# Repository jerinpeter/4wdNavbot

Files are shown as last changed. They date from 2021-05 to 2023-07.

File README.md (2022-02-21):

# A 4WD ROS Robot with autonomous navigation capability

## The Robot Harware Setup 🔧

|||
| :-----: | :-: |
| |  |
|| 

## Installation 💻

```
cd ~/catkin_ws/src

git clone https://github.com/jerinpeter/4wdNavbot.git

cd ..

catkin_make

rosdep install --from-paths src --ignore-src -r -y

```
If catkin_make shows error, install the missing dependenices using the rosdep command.  

## 3D modelling and Simulation 
The Robot was modelled in Fusion360 and converted to URDF using [fusion2urdf](https://github.com/syuntoku14/fusion2urdf).
Gazebo Pluggins for [differential drive](http://gazebosim.org/tutorials?tut=ros_gzplugins#DifferentialDrive),Odometry and [LaserScan](http://gazebosim.org/tutorials?tut=ros_gzplugins#Laser) were added to the urdf and tested in a custom made simulation environment/world in Gazebo.

### Demo video 👇

GAZEBO SIMULATION (https://www.youtube.com/watch?v=yLzaqpGkmrI)

# Simulation Setup
## Mapping 
Open a new terminal window and split it accordingly if using terminator,run the following commands 
```
roslaunch navbot_description gazebo.launch

roslaunch gmapping mapping.launch

rosrun teleop_twist_keyboard teleop_twist_keyboard.py

rviz

rosrun map_server map_saver -f newmap
```
The map is already saved in /navbot_description/maps directory if using the preset map.

## Navigation
```
roslaunch navbot_description gazebo.launch

roslaunch navbot_navigation move_base.launch

rviz

```
* After opening Rviz open the configuration file from the Rviz folder.
* Type rqt in terminal and open dynamic reconfigure pluggin, load the final_reconf_param_sim.yaml from the reconf_params folder and you are all set to give navigation goals.

# Working in brief
### Note: BOM and references are attached towards the end.

* Starting from the low-level control the Robot uses an **Arduino Mega** takes **cmd_vel** from the Jetson Nano via **ros-serial** via USB. The Arduino is also responsible for reading the encoder values and publishing it back to the Jetson Nano.
### Topics published and subscribed by Arduino
```
/cmd_vel
/right_ticks
/left_ticks 
```
* I have used **RMCS-2303** Motor drivers for controlling the Dc motors with encoders. The motor driver has inbuilt PID control implemented with the help of an STM32 MicroController.
*  The Motor driver is connected to Arduino via **UART** (Tx,RX).4 such motor drivers where used to control the 4 motors and each motors where addresed using a **unique slave-id** set via jumper pins.
* The main advantage of using this motors were that only 3 wires (Tx,Rx,Gnd) was required to control all the 4 motors,vary its speed and read the encoder values.

Motortests

* The High level control is Nvidia Jetson Nano which runs on [Jetpack](https://developer.nvidia.com/embedded/jetpack) based on ubuntu 18.04 with [ROS Melodic](http://wiki.ros.org/melodic/Installation/Ubuntu) installed.

* The Lidar is also connected to the Jetson Nano via Usb and the whole system is powered using 5v from a buck converter that steps down 12.6v from the Li-Ion Battery pack to 5V 4 amps max to power the Jetson Nano.

## ROS Setup for Mapping and Navigation 

* The arduino publishes the encoder ticks into the Jetson Nano via ros-serial which are subscribed by the [differential_drive](http://wiki.ros.org/differential_drive) package and publishes **/odom** as well as **Tf** **(odom -> base_footprint)**.

The YdLidar package is responsible for publishing the LaserScan as **/scan** data along with **Tf** **(base_link -> laser)**

### **Tf Tree**
* With the Robot Model
Tf_tree_sim

* Without Robot Model

    

# Real Robot Setup

* Before setting up and running the robot,Jetson Nano and host machine should be set up following this tutorial -> [ROS Network setup](http://wiki.ros.org/ROS/NetworkSetup)

```
roscore

rosrun rosserial_python serial_node.py /dev/ttyACM0

roslaunch ydlidar_ros yd_lidar.launch

roslaunch differential_drive tf_controller.launch

roslaunch navbot_navigation move_base.launch

rviz

```

* After running Rviz open the Navbot.rviz configuration from the Rviz folder.

* Open DynamicReconfigure from rqt gui and load final_reconf_params_real.yaml

* Give the goal location in Rviz and we are good to go!

## Components Used

| Component | Image |
| --- |:---:|
| [Nvidia Jetson Nano](https://www.tannatechbiz.com/nvidia-jetson-nano-developer-kit-b01.html) || 
| [YD-Lidar X4](https://www.amazon.in/SmartFly-info-LIDAR-053-YDLIDAR-X4/dp/B07DBYHJVQ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)|| 
|[Arduino Mega](https://robu.in/product/arduino-mega-2560-board-with-compatible-usb-cable/)|| 
| [RMCS 2303 Motor Drivers](https://robokits.co.in/motor-drives-drivers/encoder-dc-servo/rhino-dc-servo-driver-10v-30v-50w-5a-compatible-with-modbus-uart-ascii-for-encoder-dc-servo-motor)|
| [100 RPM High Precision Encoder Motors](https://robokits.co.in/motors/encoder-dc-servo/high-torque-high-precision-motor/high-torque-high-precision-encoder-dc-geared-motor-12v-100rpm)|
|[10,000Mah, 2C Li-Ion Battery](https://robokits.co.in/batteries-chargers/skycell-li-ion-battery/11.1vli-ion-batteries-9.6-12.6v/li-ion-11.1v-10000mah-2c-with-inbuilt-charger-protection) |
|[DC-DC Step Down Converter](https://robu.in/product/10a-dc-dc-step-down-adjustable-constant-voltage-module/) |
|[125mm AGV Wheels](https://robokits.co.in/robot-wheels/rubber-tracked-wheels/robot-wheel-125mm-diameter-60mm-width-for-atv) | 

## Further Work

* Modularize all the nodes into launch files for ease of use.
* Addition of the dynamic reconfigure parameters into the navigation param files.
* Using IMU and EKF for better Localization and pose estimate.
* Adding Kinect / realsense for 3D mapping,Vision applications etc.
* Addition of return to base station for charging feature.

## References

[RMCS 2303 Motor Driver Manual](https://robokits.download/downloads/RMCS-2303%20updated%20datasheet.pdf)

[RMCS 2303 Arduino Library](https://robokits.co.in/downloads/RMCS2303drive_V2.zip)

[Motor Specifications](https://robokits.download/downloads/RMCS-5013.pdf)

[ROS Navigation Tuning Guide](https://kaiyuzheng.me/documents/navguide.pdf)

[Map Float Arduino Library](https://github.com/radishlogic/MapFloat)

## [Project Photos and Videos](https://photos.app.goo.gl/16n6vmuHw6YWK7ry7)

* The photos and videos that I took during the build, will make a final video soon!

# UPDATE 12-11-2021 
 
 ## Support for Odom from T265 + TF correction

* Added Support for using Odom from Intel RealSense T265 Tracking Camera
* Added the required TF Launch files for the same
    * To use Odometry from T265 run these extra commands

 ```
roslaunch navbot_navigation tf.launch 

 ```  

 ## UPDATED Base Local Planner -> DWA to TEB

* Updated parameters can be found in the params folder

To install the same use
```
sudo apt-get install ros-noetic-teb-local-planner
```

## Added support for Xbox 360 Kinect for 3D vision -> RTAB mapping, Point Cloud Generation

[Kinect Drivers + ROS Package installation](https://aibegins.net/2020/11/22/give-your-next-robot-3d-vision-kinect-v1-with-ros-noetic/)

* After installtion the following command will open up the depth stream / PointCloud in Rviz

```
roslaunch freenect_launch freenect.launch depth_registration:=true
```

## FINAL WORKING VIDEO [Outdoor Navigation + 3D Point Cloud Generation] 👇

Final Video (https://youtu.be/Dy9fhVJdwMo)

## Contributions

Contributions are most welcome ;-)

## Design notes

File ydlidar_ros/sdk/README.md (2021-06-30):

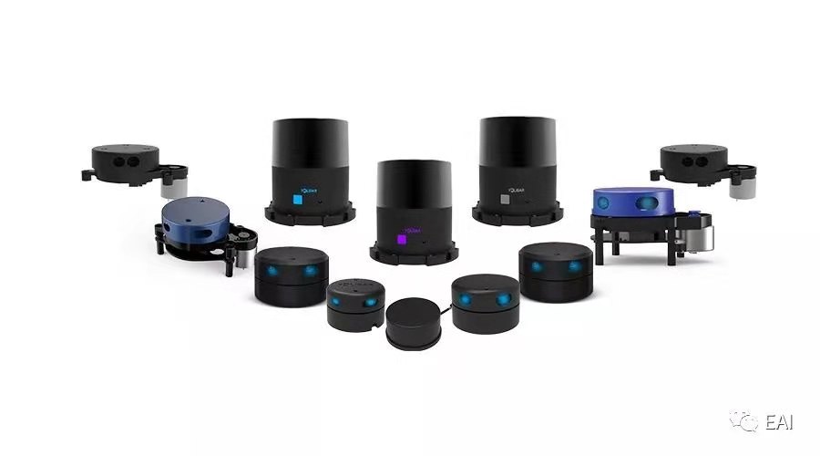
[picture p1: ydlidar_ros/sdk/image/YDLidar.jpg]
YDLIDAR


YDLIDAR SDK   
=====================================================================

# 1 Introduction

YDLIDAR(https://www.ydlidar.com/) series is a set of high-performance and low-cost LIDAR sensors, which is the perfect sensor of 2D SLAM, 3D reconstruction, multi-touch, and safety applications.

If you are using ROS (Robot Operating System), please use our open-source [ROS Driver]( https://github.com/ydlidar/ydlidar_ros) .

## 1.1 Prerequisites
* Linux
* Windows 7/10, Visual Studio 2015/2017
* C++11 compiler

## 1.2 Release Notes
| Title |  Version |  Data |
| :--- | ---:|  :--: |
| SDK |  1.4.7 | 2020-03-31  |

- [feature] support new Lidar G5 and G7.

# 2 YDLidar SDK Communication Protocol
YDLidar SDK communication protocol opens to all users. It is the communication protocol between user programs and YDLIDAR products. The protocol consists of control commands and data format. Please refer to the [YDLidar SDK Communication Protocol](include/ydlidar_protocol.h) for detailed information.

# 3 YDLidar SDK

YDLidar SDK provides the implementation of control commands and Laser scan data transmission, as well as the C/C++ API. The basic structure of YDLidar SDK is shown as below:

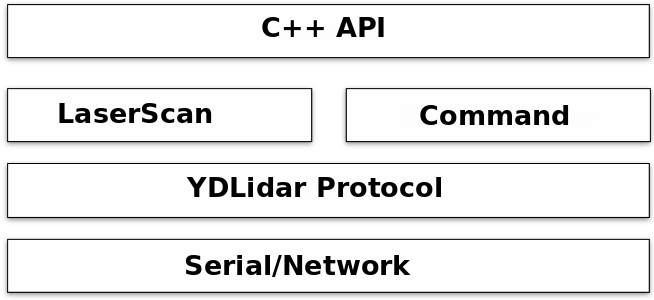
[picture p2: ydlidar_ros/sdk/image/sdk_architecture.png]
YDLidar SDK Architecture


 Serial or network is used for communication between YDLidar SDK and LiDAR sensors. Please refer to the YDLidar SDK Communication Protocol for further information. LaserScan supports Laser Scan Data transmission, while Command handler receives and sends control commands. And the C++ API is based on Command and LaserScan Hander.

The YDLidar LiDAR sensors can be connected to host directly by serial or through the YDLidar Adapter board. YDLidar SDK supports both connection methods. When LiDAR units are connected to host directly by Serial, the host will establish communication with each LiDAR unit individually. And if the LiDAR units connect to host through Adapter board, then the host only communicates with the YDLidar Adapter board while the Adapter Board communicates with each LiDAR unit.

# 4 YDLidar SDK API

YDLidar SDK API provides a set of C++ style functions which can be conveniently integrated in C/C++ programs. Please refer to the [YDLidar SDK API Reference](doc/html/index.html) for further information.

## 4.1 Installation
The installation procedures in Ubuntu 18.04/16.04/14.04 LTS and Windows 7/10 are shown here as examples. For Ubuntu 18.04/16.04/14.04 32-bit LTS and Mac, you can get it in [YDLidar-SDK wiki](https://github.com/YDLIDAR/YDLidar-SDK/wiki).
### 4.1.1 Ubuntu 18.04/16.04/14.04 LTS
#### Dependencies
YDLidar SDK requires [CMake 2.8.2+](https://cmake.org/) as dependencies. You can install these packages using apt:
```
sudo apt install cmake pkg-config
```
#### Compile YDLidar SDK
In the YDLidar SDK directory, run the following commands to compile the project:
```
git clone https://github.com/YDLIDAR/sdk.git
cd sdk/build
cmake ..
make
sudo make install
```
### 4.1.2 Windows 7/10
#### Dependencies
YDLidar SDK supports Visual Studio 2015/2017 and requires [CMake 2.8.2+](https://cmake.org/) as dependencies. [vcpkg](https://github.com/Microsoft/vcpkg) is recommended for building the dependency libraries as follows:
For the 32-bit project:
```
.\vcpkg install cmake
.\vcpkg integrate install
```
For the 64-bit project:
```
.\vcpkg install cmake:x64-windows
.\vcpkg integrate install
```
Then, in the YDLidar SDK directory, run the following commands to create the Visual Studio solution file. Please replace [vcpkgroot] with your vcpkg installation path.
Generate the 32-bit project:
```
cd build && \
cmake .. "-DCMAKE_TOOLCHAIN_FILE=[vcpkgroot]\scripts\buildsystems\vcpkg.cmake"
```
Generate the 64-bit project:
```
cd build && \
cmake .. -G "Visual Studio 15 2017 Win64" "-DCMAKE_TOOLCHAIN_FILE=[vcpkgroot]\scripts\buildsystems\vcpkg.cmake"
```
#### Compile YDLidar SDK
You can now compile the YDLidar SDK in Visual Studio.

## 4.2 Run YDLidar SDK Sample
Three samples are provided in samples, which demonstrate how to configure YDLidar LiDAR units and receive the laser scan data when directly connecting YDLidar SDK to LiDAR units or by using a YDLidar Adapter board, respectively. The sequence diagram is shown as below:



### 4.2.1 Ubuntu 18.04/16.04 /14.04 LTS
For Ubuntun 18.04/16.04/14.04 LTS, run the *ydlidar_test* if connect with the Triangle LiDAR unit(s) or TOF LiDAR unit(s):
```
./ydlidar_test
```
### 4.2.2 Windows 7/10
After compiling the YDLidar SDK as shown in section 4.1.2, you can find `ydlidar_test.exe` in the {sdk}\build\Debug or {sdk}\build\Release folder, respectively, which can be run directly.

Then you can see SDK initializing the information as below:



Then you can see SDK Scanning the information as below:

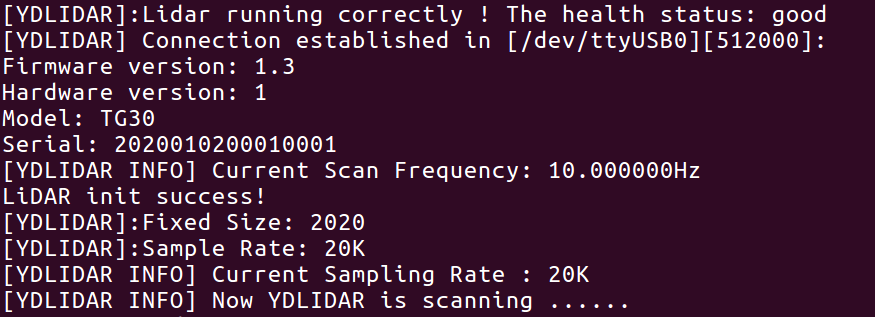
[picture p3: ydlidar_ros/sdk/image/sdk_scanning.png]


### 4.3 Connect to the specific LiDAR units

Samples we provided will connect all the LiDAR device in you USB in default.There are two ways to connect the specific units:

* run sample with input options in serial port.

* run sample with input options in network.

#### 4.3.1 Program Options

We provide the following program options for connecting the specific units :
```
[Please select the lidar baudrate:]: input LiDAR BaudRate.
[Whether the Lidar is one-way communication[yes/no]:]: Whether The Current LiDAR is single-channel.
[Whether the Lidar is a TOF Lidar [yes/no]:]: Whether The Current LiDAR is TOF Type LiDAR.
[Please enter the lidar scan frequency[5-12]:]:input LiDAR Scan Frequency.
```
Note: Specific LiDAR Input Options, refer to [DataSet](#7-dataset)

Here is the example:
```
__   ______  _     ___ ____    _    ____
\ \ / /  _ \| |   |_ _|  _ \  / \  |  _ \ 
 \ V /| | | | |    | || | | |/ _ \ | |_) | 
  | | | |_| | |___ | || |_| / ___ \|  _ <
  |_| |____/|_____|___|____/_/   \_\_| \_\ 

Baudrate:
0. 115200
1. 128000
2. 153600
3. 230400
4. 512000
Please select the lidar baudrate:4
Whether the Lidar is one-way communication[yes/no]:no
Whether the Lidar is a TOF Lidar [yes/no]:yes
Please enter the lidar scan frequency[5-12]:10
```

# 5 SDK Flow Chart
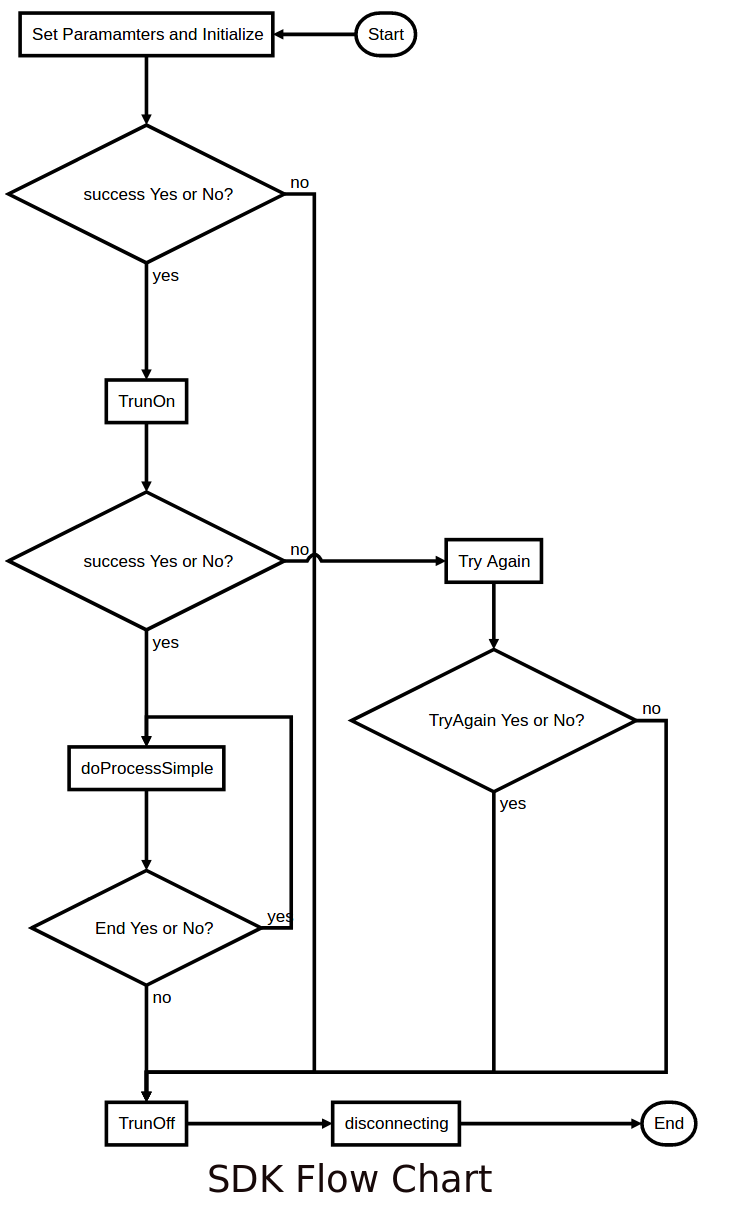
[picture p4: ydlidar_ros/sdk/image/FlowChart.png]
FlowChart Flow Chart


# 6 TOF LiDAR
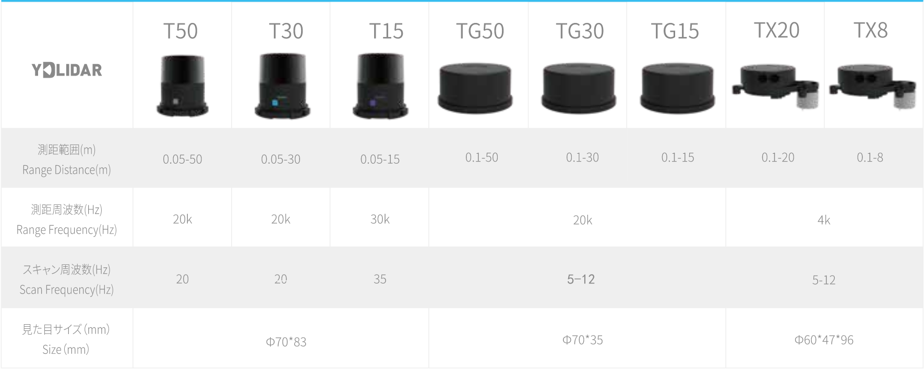
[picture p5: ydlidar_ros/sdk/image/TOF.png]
TOF


# 7 Dataset 
|LIDAR | Model  |  Baudrate |  SampleRate(K) | Range(m)  		 |  Frequency(HZ) | Intenstiy(bit) | SingleChannel | voltage(V)|
| :--- |:--:|:--:|:--:|:--:|:--:|:--:|:--:|:--:|
| F4 | 1	 |  115200 | 4 |  0.12~12 | 5~12 | false | false 	  | 4.8~5.2 |
| S4 | 4	 |  115200 | 4 |  0.10~8.0 | 5~12 (PWM) | false | false 	  | 4.8~5.2 |
| S4B | 4/11 |  153600 | 4 |  0.10~8.0 | 5~12(PWM) | true(8) | false 	  | 4.8~5.2 |
| S2 | 4/12 |  115200 | 3 |  0.10~8.0 	| 4~8(PWM) | false | true 		  | 4.8~5.2 |
| G4 | 5	 |  230400 | 9/8/4 |  0.28/0.26/0.1~16| 5~12 	  | false | false 	  | 4.8~5.2 |
| X4 | 6	 |  128000 | 5 |  0.12~10 		| 5~12(PWM) | false | false 	  | 4.8~5.2 |
| X2/X2L | 6	 |  115200 | 3 |  0.10~8.0 	| 4~8(PWM) | false | true 		  | 4.8~5.2 |
| G4PRO | 7	 |  230400 | 9/8/4 |  0.28/0.26/0.1~16| 5~12 	  | false | false 	  | 4.8~5.2 |
| F4PRO | 8	 |  230400 | 4/6 |  0.12~12 | 5~12 	  | false | false 	  | 4.8~5.2 |
| R2 | 9	 |  230400 | 5 |  0.12~16 		| 5~12 	  | false | false 	  | 4.8~5.2 |
| G6 | 13 |  512000 | 18/16/8 |  0.28/0.26/0.1~25| 5~12 	  | false | false 	  | 4.8~5.2 |
| G2A | 14	 |  230400 | 5 |  0.12~12 | 5~12 	  | false | false 	  | 4.8~5.2 |
| G2 | 15		|  230400 | 5 |  0.28~16 		| 5~12 	  | true(8) | false 	  | 4.8~5.2 |
| G2C | 16		|  115200 | 4 |  0.1~12 	| 5~12 	  | false 	 | false 	  | 4.8~5.2 |
| G4B | 17		|  512000 | 10 |  0.12~16 | 5~12 	  | true(10) | false 	  | 4.8~5.2 |
| G4C | 18		|  115200 | 4 |  0.1~12		 | 5~12 | false | false 	  | 4.8~5.2 |
| G1 | 19		|  230400 | 9 |  0.28~16 | 5~12 	  | false | false 	  | 4.8~5.2 |
| G5 | 20	 |  230400 | 9/8/4 |  0.28/0.26/0.1~16| 5~12 	  | false | false 	  | 4.8~5.2 |
| G7 | 21 |  512000 | 18/16/8 |  0.28/0.26/0.1~25| 5~12 	  | false | false 	  | 4.8~5.2 |
| TX8 　 | 100	 |  115200 | 4 |  0.1~8 	 | 4~8(PWM) | false | true 	  | 4.8~5.2 |
| TX20 　| 100	 |  115200 | 4 |  0.1~20 	 | 4~8(PWM) | false | true 	  | 4.8~5.2 |
| TG15 　| 100	 |  512000 | 20/18/10 |  0.05~15 	| 3~16 	  | false | false 	  | 4.8~5.2 |
| TG30 　| 101	 |  512000 | 20/18/10 |  0.05~30 	| 3~16 	  | false | false 	  | 4.8~5.2 |
| TG50 　| 102	 |  512000 | 20/18/10 |  0.05~50 	| 3~16 	  | false | false 	  | 4.8~5.2 |

   Note: PWM option speed control requires external PWM wave.
   
# 8 Licence

The SDK itself is licensed under BSD [license](license)

# 9 Support

You can get support from YDLidar with the following methods:
* Send email to support@ydlidar.com with a clear description of your problem and your setup
* Github Issues

# 10 Contact EAI
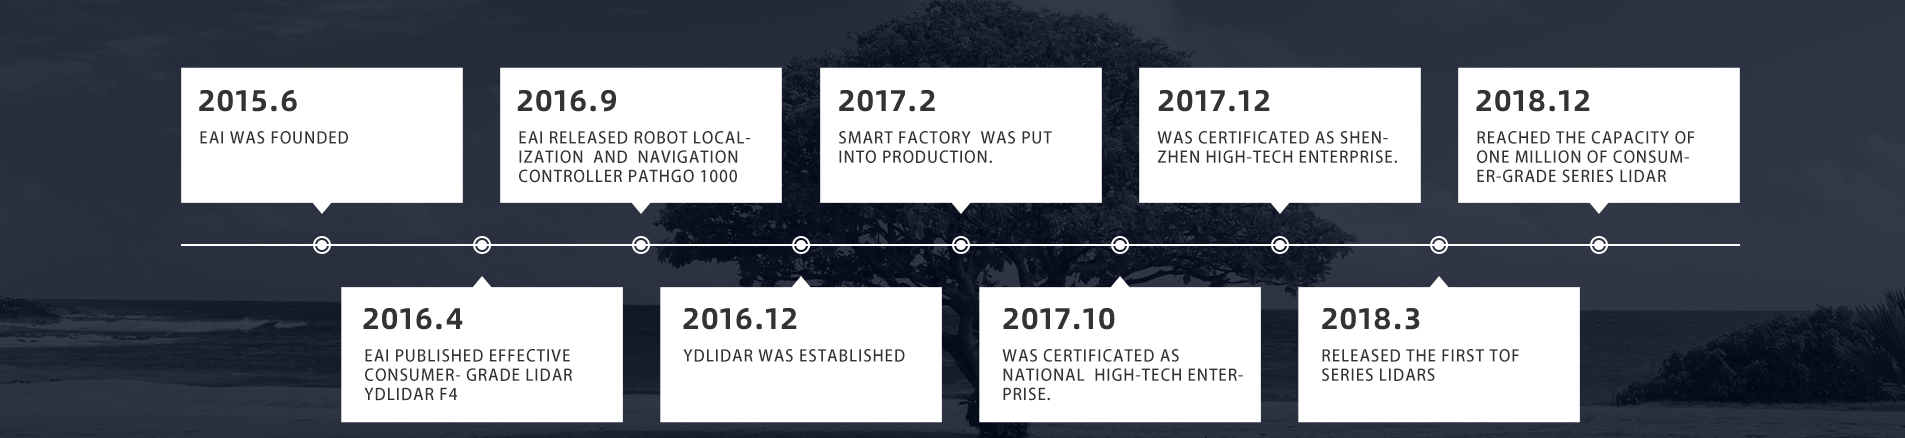
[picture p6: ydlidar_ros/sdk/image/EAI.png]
Development Path


If you have any extra questions, please feel free to [contact us](http://www.ydlidar.cn/cn/contact)

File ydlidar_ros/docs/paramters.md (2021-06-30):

# ROS Paramters Table

## Paramters Description
| Parameter | Type | Description |
|---|---|---|
| `port` 		| String 	| port of lidar (ex. /dev/ttyUSB0) 		|
| `baudrate` 	| int 	| baudrate of lidar (ex. 230400) 				|
| `frame_id` 	| String 	| TF frame of sensor, default: `laser_frame` 		|
| `isSingleChannel` | bool 	| Whether LiDAR is a single-channel, default: false	|
| `resolution_fixed` | bool 	| Fixed angluar resolution, default: true 	|
| `auto_reconnect` | bool 	| Automatically reconnect the LiDAR, default: true 	|
| `reversion` 	| bool 	| Reversion LiDAR, default: true  					|
| `isTOFLidar` 	| bool 	| Whether LiDAR is TOF Type, default: false  		|
| `angle_min` 	| float 	| Minimum Valid Angle, defalut: -180.0 			|
| `angle_max` 	| float 	| Maximum Valid Angle, defalut: 180.0 			|
| `range_min` 	| float 	| Minimum Valid range, defalut: 0.01m 			|
| `range_max` 	| float 	| Maximum Valid range, defalut: 64.0m 			|
| `ignore_array` | String 	| LiDAR filtering angle area, default: "" 			|
| `samp_rate` 	| int 	| sampling rate of lidar, default: 9 				|
| `frequency` 	| float 	| scan frequency of lidar,default: 10.0 			|

## Baudrate Table

| LiDAR 					| baudrate | 
|---|---|
|F4/S2/X2/X2L/S4/TX8/TX20/G4C 		| 115200			|
|X4 					| 128000			|
|S4B 				| 153600			|
|G1/G2/R2/G4/G4PRO/F4PRO 	| 230400			|
|G6/TG15/TG30/TG50			 	| 512000			|

## SingleChannel Table

| LiDAR 							| isSingleChannel | 
|---|---|
|G1/G2/G4/G6/F4/F4PRO/S4/S4B/X4/R2/G4C 	| false			|
|S2/X2/X2L 						| true			|
|TG15/TG30/TG50 				| false			|
|TX8/TX20 							| true			|

##　isToFLidar Table

| LiDAR 									| isTOFLidar | 
|---|---|
|G1/G2/G4/G6/F4/F4PRO/S4/S4B/X4/R2/G4C/S2/X2/X2L 	| false			|
|TG15/TG30/TG50/TX8/TX20 				| true			|

## Sampling Rate Table

| LiDAR 		| samp_rate | 
|---|---|
|G4/F4 		| 4,8,9			 |
|F4PRO 		| 4,6 			 |
|G6 		| 8,16,18			 |
|G1/G2/R2/X4 		| 5				 |
|S4/S4B/G4C/TX8/TX20 	| 4			 	 |
|S2 		| 3			 	 |
|TG15/TG30/TG50 | 10,18,20		 |

## Frequency Table

| LiDAR 					| frequency | 
|---|---|
|G1/G2/R2/G6/G4/G4PRO/F4/F4PRO	| 5-12Hz			 |
|S4/S4B/S2/TX8/TX20/X4 			| Not Support		 |
|TG15/TG30/TG50 			| 3-16Hz			 |

Note: For unsupported LiDARs, adjusting the scanning frequency requires external access to PWM speed control.

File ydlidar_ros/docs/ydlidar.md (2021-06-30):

# YDLIDAR ROS Package Download and Build
## Step1: create a ROS workspace, if there is no workspace, othereise Skip to Step2
#### Linux/OS X
	$mkdir -p ~/ydlidar_ros_ws/src
	$cd ~/ydlidar_ros_ws/src
#### Windows
	$md \dev\ydlidar_ros_ws\src
	$cd \dev\ydlidar_ros_ws\src
	
## Step2: clone ydlidar ros package
	$git clone https://github.com/YDLIDAR/ydlidar_ros
	
## Step3: Build [ydlidar_ros](https://github.com/YDLIDAR/ydlidar_ros) package
	$cd ..
	$catkin_make
	
Note: Set ROS Workspace Environment Variables

	$echo "source ~/ydlidar_ros_ws/devel/setup.bash" >> ~/.bashrc
	$source ~/.bashrc
	
## Step4:Configure LiDAR [paramters](../launch/lidar.launch)
	<launch>
  	<node name="ydlidar_node"  pkg="ydlidar_ros"  type="ydlidar_node" output="screen" respawn="false" >
    		<param name="port"         type="string" value="/dev/ydlidar"/>  
    		<param name="baudrate"         type="int" value="230400"/>  
    		<param name="frame_id"     type="string" value="laser_frame"/>
    		<param name="resolution_fixed"    type="bool"   value="true"/>
    		<param name="auto_reconnect"    type="bool"   value="true"/>
    		<param name="reversion"    type="bool"   value="true"/>
    		<param name="angle_min"    type="double" value="-180" />
    		<param name="angle_max"    type="double" value="180" />
    		<param name="range_min"    type="double" value="0.1" />
    		<param name="range_max"    type="double" value="16.0" />
    		<param name="ignore_array" type="string" value="" />
    		<param name="frequency"    type="double" value="10"/>
    		<param name="isTOFLidar"    type="bool"   value="false"/>
 	 </node>
  	<node pkg="tf" type="static_transform_publisher" name="base_link_to_laser4"
    args="0.2245 0.0 0.2 0.0 0.0  0.0 /base_footprint /laser_frame 40" />
	</launch>

Note: How to configure paramters, see [here](paramters.md)
  
## Step5:Create serial port Alias[/dev/ydlidar] 
	$chmod 0777 src/ydlidar_ros/startup/*
	$sudo sh src/ydlidar_ros/startup/initenv.sh
Note: After completing the previous operation, replug the LiDAR again.
  
## Step6:Run ydlidar_ros node
	
	$roslaunch ydlidar_ros lidar.launch

	$rosrun ydlidar_ros ydlidar_client
	 
or 

	$roslaunch ydlidar_ros lidar_view.launch

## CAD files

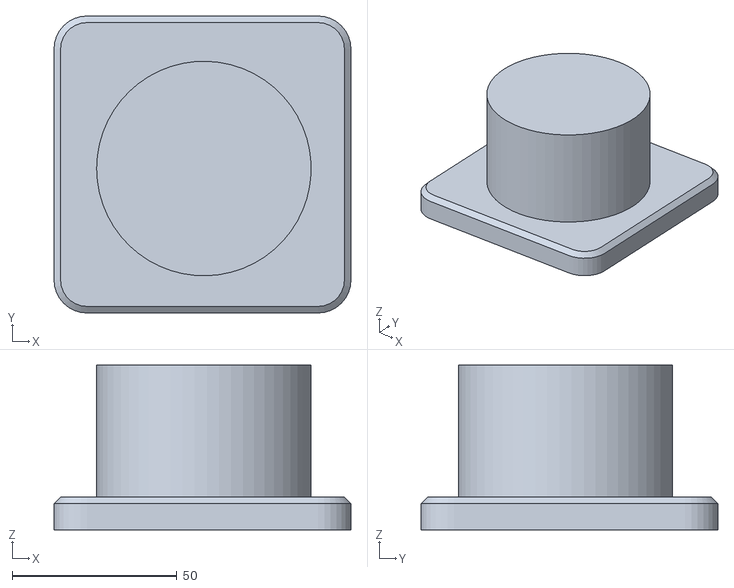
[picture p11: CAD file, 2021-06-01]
navbot_description/meshes/laser_link_v1_1.stl
90.0 x 90.0 x 50.0

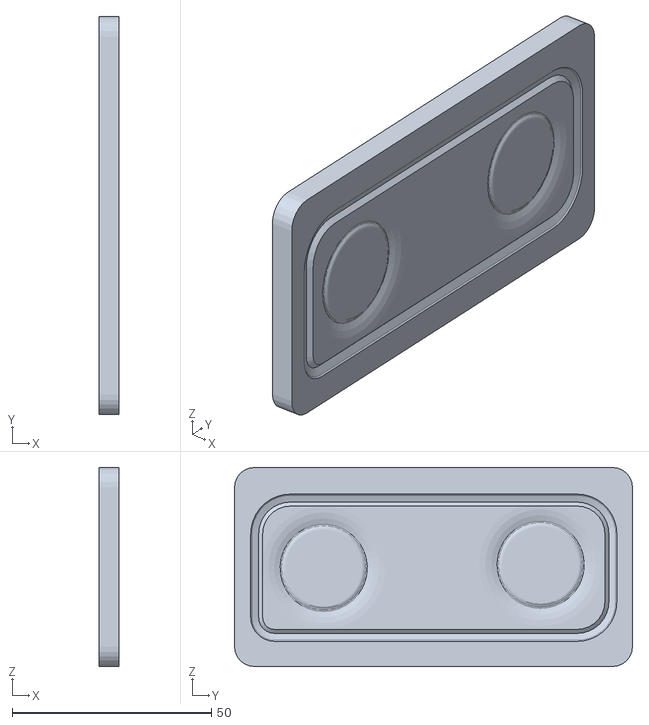
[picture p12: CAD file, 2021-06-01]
navbot_description/meshes/camera_link_v1_1.stl
5.00 x 100.0 x 50.0

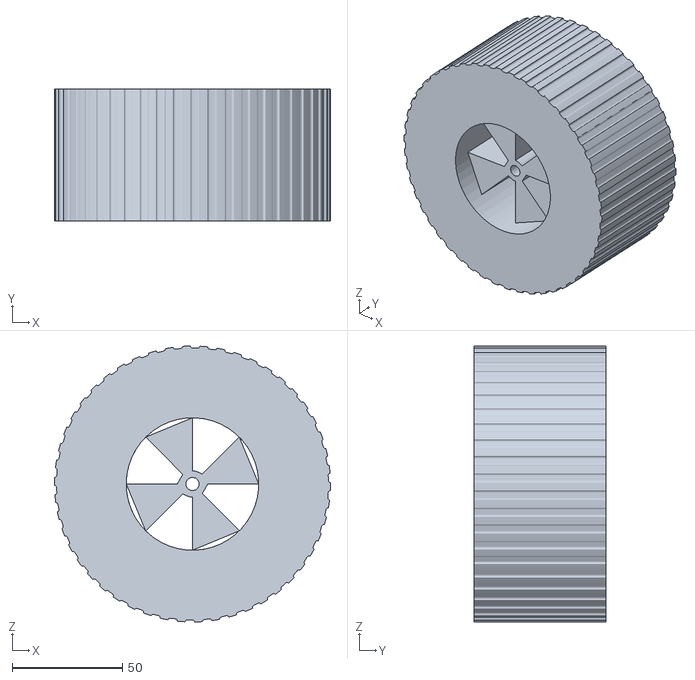
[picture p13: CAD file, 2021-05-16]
navbot_description/meshes/back_left_1.stl
125.0 x 60.0 x 125.0

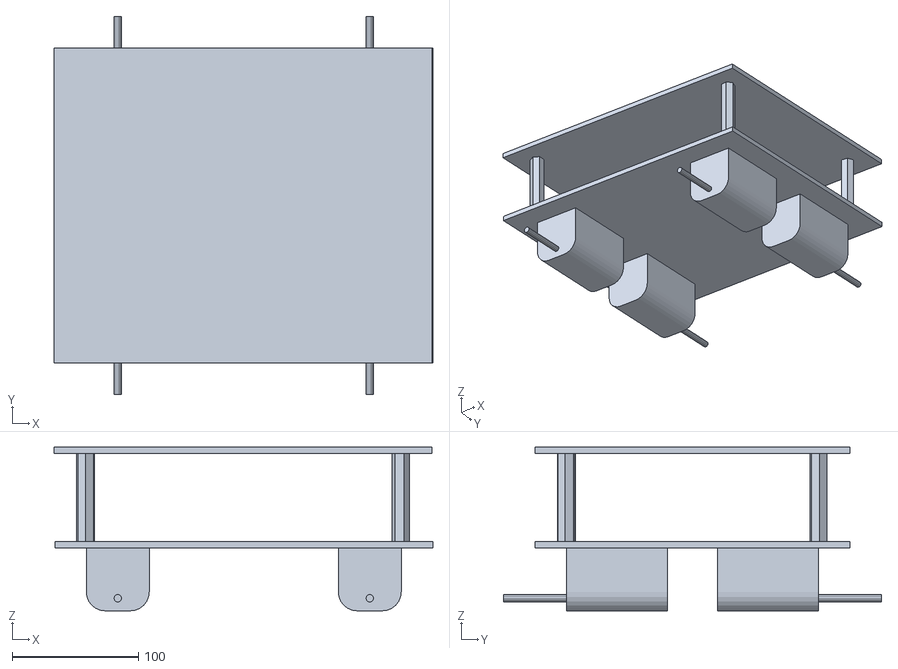
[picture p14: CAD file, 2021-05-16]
navbot_description/meshes/base_link.stl
300.4 x 300.0 x 129.9

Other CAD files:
navbot_description/meshes/front_left_1.stl
navbot_description/meshes/front_right_1.stl
navbot_description/meshes/back_right_1.stl
navbot_description/meshes/laser_link_1.stl
navbot_description/meshes/camera_link_1.stl

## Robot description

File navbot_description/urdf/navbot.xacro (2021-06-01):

<?xml version="1.0" ?>
<robot name="navbot" xmlns:xacro="http://www.ros.org/wiki/xacro">

<xacro:include filename="$(find navbot_description)/urdf/materials.xacro" />
<xacro:include filename="$(find navbot_description)/urdf/navbot.trans" />
<xacro:include filename="$(find navbot_description)/urdf/navbot.gazebo" />
<xacro:include filename="$(find navbot_description)/urdf/navbot_gazebo_plugins.xacro" />
<link name="base_link">
  <inertial>
    <origin rpy="0 0 0" xyz="0.0003147036812539107 8.654508451147519e-05 0.10819103947899564"/>
    <mass value="12.261671363009004"/>
    <inertia ixx="0.081478" ixy="-0.0" ixz="9.1e-05" iyy="0.132969" iyz="2.5e-05" izz="0.169987"/>
  </inertial>
  <visual>
    <origin rpy="0 0 0" xyz="0 0 0"/>
    <geometry>
      <mesh filename="package://navbot_description/meshes/base_link.stl" scale="0.001 0.001 0.001"/>
    </geometry>
    <material name="silver"/>
  </visual>
  <collision>
    <origin rpy="0 0 0" xyz="0 0 0"/>
    <geometry>
      <mesh filename="package://navbot_description/meshes/base_link.stl" scale="0.001 0.001 0.001"/>
    </geometry>
  </collision>
</link>

<link name="back_right_1">
  <inertial>
    <origin rpy="0 0 0" xyz="-4.597357573521421e-07 -0.02052480177758853 3.5268927792847515e-07"/>
    <mass value="4.878358553104739"/>
    <inertia ixx="0.006717" ixy="-0.0" ixz="-0.0" iyy="0.010579" iyz="-0.0" izz="0.006717"/>
  </inertial>
  <visual>
    <origin rpy="0 0 0" xyz="0.099572 0.149882 -0.060076"/>
    <geometry>
      <mesh filename="package://navbot_description/meshes/back_right_1.stl" scale="0.001 0.001 0.001"/>
    </geometry>
    <material name="silver"/>
  </visual>
  <collision>
    <origin rpy="0 0 0" xyz="0.099572 0.149882 -0.060076"/>
    <geometry>
      <mesh filename="package://navbot_description/meshes/back_right_1.stl" scale="0.001 0.001 0.001"/>
    </geometry>
  </collision>
</link>

<link name="front_right_1">
  <inertial>
    <origin rpy="0 0 0" xyz="-4.5917696378516837e-07 -0.02052480177758842 3.532853243698453e-07"/>
    <mass value="4.878358553104739"/>
    <inertia ixx="0.006717" ixy="-0.0" ixz="-0.0" iyy="0.010579" iyz="0.0" izz="0.006717"/>
  </inertial>
  <visual>
    <origin rpy="0 0 0" xyz="-0.100428 0.149882 -0.060076"/>
    <geometry>
      <mesh filename="package://navbot_description/meshes/front_right_1.stl" scale="0.001 0.001 0.001"/>
    </geometry>
    <material name="silver"/>
  </visual>
  <collision>
    <origin rpy="0 0 0" xyz="-0.100428 0.149882 -0.060076"/>
    <geometry>
      <mesh filename="package://navbot_description/meshes/front_right_1.stl" scale="0.001 0.001 0.001"/>
    </geometry>
  </collision>
</link>

<link name="back_left_1">
  <inertial>
    <origin rpy="0 0 0" xyz="-4.591769638545573e-07 0.02052395350161601 3.5268927771336944e-07"/>
    <mass value="4.878358553104739"/>
    <inertia ixx="0.006717" ixy="0.0" ixz="0.0" iyy="0.010579" iyz="0.0" izz="0.006717"/>
  </inertial>
  <visual>
    <origin rpy="0 0 0" xyz="0.099572 -0.150118 -0.060076"/>
    <geometry>
      <mesh filename="package://navbot_description/meshes/back_left_1.stl" scale="0.001 0.001 0.001"/>
    </geometry>
    <material name="silver"/>
  </visual>
  <collision>
    <origin rpy="0 0 0" xyz="0.099572 -0.150118 -0.060076"/>
    <geometry>
      <mesh filename="package://navbot_description/meshes/back_left_1.stl" scale="0.001 0.001 0.001"/>
    </geometry>
  </collision>
</link>

<link name="front_left_1">
  <inertial>
    <origin rpy="0 0 0" xyz="-4.5917696392394625e-07 0.020523953501616038 3.5328532416167846e-07"/>
    <mass value="4.878358553104739"/>
    <inertia ixx="0.006717" ixy="0.0" ixz="0.0" iyy="0.010579" iyz="0.0" izz="0.006717"/>
  </inertial>
  <visual>
    <origin rpy="0 0 0" xyz="-0.100428 -0.150118 -0.060076"/>
    <geometry>
      <mesh filename="package://navbot_description/meshes/front_left_1.stl" scale="0.001 0.001 0.001"/>
    </geometry>
    <material name="silver"/>
  </visual>
  <collision>
    <origin rpy="0 0 0" xyz="-0.100428 -0.150118 -0.060076"/>
    <geometry>
      <mesh filename="package://navbot_description/meshes/front_left_1.stl" scale="0.001 0.001 0.001"/>
    </geometry>
  </collision>
</link>

<link name="laser_link_v1_1">
  <inertial>
    <origin rpy="0 0 0" xyz="0.0002638330985168125 -0.0007615524008374664 0.020624066504128902"/>
    <mass value="1.6657432797148926"/>
    <inertia ixx="0.001074" ixy="0.0" ixz="-4e-06" iyy="0.001074" iyz="1.2e-05" izz="0.001371"/>
  </inertial>
  <visual>
    <origin rpy="0 0 0" xyz="-0.0 -0.0 -0.18"/>
    <geometry>
      <mesh filename="package://navbot_description/meshes/laser_link_v1_1.stl" scale="0.001 0.001 0.001"/>
    </geometry>
    <material name="silver"/>
  </visual>
  <collision>
    <origin rpy="0 0 0" xyz="-0.0 -0.0 -0.18"/>
    <geometry>
      <mesh filename="package://navbot_description/meshes/laser_link_v1_1.stl" scale="0.001 0.001 0.001"/>
    </geometry>
  </collision>
</link>

<link name="camera_link_v1_1">
  <inertial>
    <origin rpy="0 0 0" xyz="-0.010094496944980769 1.27997814036277e-05 -0.14999905153125456"/>
    <mass value="0.18735731616487916"/>
    <inertia ixx="0.000194" ixy="-0.0" ixz="-0.0" iyy="4e-05" iyz="0.0" izz="0.000155"/>
  </inertial>
  <visual>
    <origin rpy="0 0 0" xyz="-0.150428 -0.000118 -0.280076"/>
    <geometry>
      <mesh filename="package://navbot_description/meshes/camera_link_v1_1.stl" scale="0.001 0.001 0.001"/>
    </geometry>
    <material name="silver"/>
  </visual>
  <collision>
    <origin rpy="0 0 0" xyz="-0.150428 -0.000118 -0.280076"/>
    <geometry>
      <mesh filename="package://navbot_description/meshes/camera_link_v1_1.stl" scale="0.001 0.001 0.001"/>
    </geometry>
  </collision>
</link>

<joint name="Rev1" type="continuous">
  <origin rpy="0 0 0" xyz="-0.099572 -0.149882 0.060076"/>
  <parent link="base_link"/>
  <child link="back_right_1"/>
  <axis xyz="0.0 1.0 -0.0"/>
</joint>

<joint name="Rev3" type="continuous">
  <origin rpy="0 0 0" xyz="0.100428 -0.149882 0.060076"/>
  <parent link="base_link"/>
  <child link="front_right_1"/>
  <axis xyz="0.0 1.0 -0.0"/>
</joint>

<joint name="Rev4" type="continuous">
  <origin rpy="0 0 0" xyz="-0.099572 0.150118 0.060076"/>
  <parent link="base_link"/>
  <child link="back_left_1"/>
  <axis xyz="-0.0 1.0 0.0"/>
</joint>

<joint name="Rev5" type="continuous">
  <origin rpy="0 0 0" xyz="0.100428 0.150118 0.060076"/>
  <parent link="base_link"/>
  <child link="front_left_1"/>
  <axis xyz="-0.0 1.0 0.0"/>
</joint>

<joint name="Rigid8" type="fixed">
  <origin rpy="0 0 0" xyz="0.0 0.0 0.19"/>
  <parent link="base_link"/>
  <child link="laser_link_v1_1"/>
</joint>

<joint name="Rigid9" type="fixed">
  <origin rpy="0 0 0" xyz="0.150428 0.000118 0.280076"/>
  <parent link="base_link"/>
  <child link="camera_link_v1_1"/>
</joint>

</robot>

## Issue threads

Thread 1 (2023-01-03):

Trying to build this-Questions.

t33xdr, 2023-01-03:
Great work. Could you add the wiring diagram? Curious on how to implement the skid steer(from navbot_description) . How to combine left [( front ,back) motors as one topic] & [right] as another while using individual controllers for four motors as you did. Noted that rmcs gets data from 2 slave ids -#2 & #4.Thanks.

jerinpeter, 2023-01-03:
**Wiring**
Wiring is pretty straight forward
-  Assign unique Slave ID's to all 4 motors, you can do so by referring to the rmcs manual.
- Connect the TX, RX, GND of all the motors in parallel.
- From this connect to the TX, RX, and GND of the Arduino Mega.
- Upload the code, Specify the code in the code and you are good to GO!

**Skid Steer Implementation**
For the simulation, I have used the skid steer gazebo plugin. which takes care of everything and can accept cmd_vel and drive the Robot.

I have also implemented **diff_drive_controller**  from `ros_control` in the simulation but as it needs an hardware interface code, I haven't implemented that in the real robot.

You can refer to the code for the same [here](https://github.com/jerinpeter/navbot_diff_drive_control)

Currently,I haven't implemented a controller for the real robot. The RMCS 2303 motor drivers do have an inbuilt PID controller running in them which will do the RPM correction.

In the Arduino Code I have written, I have treated the **left** [front, back] and **right**[ front, back] as one and wrote code in such a way that left wheel and right velocity calculated goes to both the front and back wheels respectively.

t33xdr, 2023-01-03:
Thanks for the prompt reply,Jerin. I'll supplement this info. by going through the RMCS docs.Cheers!

Closed 2023-01-03.

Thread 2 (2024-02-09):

How can I use this code in ROS2?

siddharthumakarthikeyan, 2024-02-09:
Thanks for sharing your knowledge. I'm really excited to know how to control these RMCS drivers using ROS2. Thanks.

jerinpeter, 2024-02-09:
As of now, you can either try to interface it with ROS2Arduino library and make it communicate with ROS2 or else you can use micro-ros. Also it is also possible to write a python script to read in the UART values from the motor driver and write your own node to interface the motors with ROS 2.

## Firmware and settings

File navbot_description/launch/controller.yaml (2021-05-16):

navbot_controller:
  # Publish all joint states -----------------------------------
  joint_state_controller:
    type: joint_state_controller/JointStateController
    publish_rate: 50

  # Position Controllers --------------------------------------
  Rev1_position_controller:
    type: effort_controllers/JointPositionController
    joint: Rev1
    pid: {p: 100.0, i: 0.01, d: 10.0}
  Rev3_position_controller:
    type: effort_controllers/JointPositionController
    joint: Rev3
    pid: {p: 100.0, i: 0.01, d: 10.0}
  Rev4_position_controller:
    type: effort_controllers/JointPositionController
    joint: Rev4
    pid: {p: 100.0, i: 0.01, d: 10.0}
  Rev5_position_controller:
    type: effort_controllers/JointPositionController
    joint: Rev5
    pid: {p: 100.0, i: 0.01, d: 10.0}

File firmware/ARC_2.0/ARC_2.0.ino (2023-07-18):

#include <ros.h>
#include <RMCS2303drive.h>
#include <geometry_msgs/Twist.h>
#include <std_msgs/Int32.h>

#include "MapFloat.h"

RMCS2303 rmcs;  // creation of motor driver object
// slave ids to be set on the motor driver refer to the manual in the reference section
byte slave_id1 = 1;
byte slave_id2 = 2;
byte slave_id3 = 3;
byte slave_id4 = 4;

ros::NodeHandle nh;        // Node handle Object
geometry_msgs::Twist msg;  // msg variable of data type twist

std_msgs::Int32 lwheel;  // for storing left encoder value
std_msgs::Int32 rwheel;  // for storing right encoder value

// Publisher object with topic names left_ticks and right_ticks for publishing Enc Values
ros::Publisher left_ticks("left_ticks", &lwheel);
ros::Publisher right_ticks("right_ticks", &rwheel);
// Make sure to specify the correct values here
//*******************************************
double wheel_rad = 0.0625, wheel_sep = 0.300;  // wheel radius and wheel sepration in meters.
//******************************************
double w_r = 0, w_l = 0;
double speed_ang;
double speed_lin;
double leftPWM;
double rightPWM;

void messageCb(const geometry_msgs::Twist& msg)  // cmd_vel callback function definition
{
  speed_lin = max(min(msg.linear.x, 1.0f), -1.0f);   // limits the linear x value from -1 to 1
  speed_ang = max(min(msg.angular.z, 1.0f), -1.0f);  // limits the angular z value from -1 to 1

  // Kinematic equation for finding the left and right velocities
  w_r = (speed_lin / wheel_rad) + ((speed_ang * wheel_sep) / (2.0 * wheel_rad));
  w_l = (speed_lin / wheel_rad) - ((speed_ang * wheel_sep) / (2.0 * wheel_rad));

  if (w_r == 0)
  {
    rightPWM = 0;
    rmcs.Disable_Digital_Mode(slave_id1,0);
    rmcs.Disable_Digital_Mode(slave_id2,0);  // if right motor velocity is zero set right pwm to zero and disabling motors
    rmcs.Disable_Digital_Mode(slave_id3,0);
    rmcs.Disable_Digital_Mode(slave_id4,0);
  }
  else
    rightPWM = mapFloat(fabs(w_r), 0.0, 18.0, 1500,17200);  // mapping the right wheel velocity with respect to Motor PWM values

  if (w_l == 0)
  {
    leftPWM = 0;
    rmcs.Disable_Digital_Mode(slave_id1,0);
    rmcs.Disable_Digital_Mode(slave_id2,0);  // if left motor velocity is zero set left pwm to zero and disabling motors
    rmcs.Disable_Digital_Mode(slave_id3,0);
    rmcs.Disable_Digital_Mode(slave_id4,0);
  }

  else
    leftPWM = mapFloat(fabs(w_l), 0.0, 18.0, 1500,
                       17200);  // mapping the right wheel velocity with respect to Motor PWM values

  rmcs.Speed(slave_id1,rightPWM);
  rmcs.Speed(slave_id2,rightPWM);
  rmcs.Speed(slave_id3,leftPWM);
  rmcs.Speed(slave_id4,leftPWM);

  if (w_r > 0 && w_l > 0)
  {
    rmcs.Enable_Digital_Mode(slave_id1,1);
    rmcs.Enable_Digital_Mode(slave_id2,1);  // forward condition
    rmcs.Enable_Digital_Mode(slave_id3,0);
    rmcs.Enable_Digital_Mode(slave_id4,0);
  }

  else if (w_r < 0 && w_l < 0)
  {
    rmcs.Enable_Digital_Mode(slave_id1,0);
    rmcs.Enable_Digital_Mode(slave_id2,0);  // backward condition
    rmcs.Enable_Digital_Mode(slave_id3,1);
    rmcs.Enable_Digital_Mode(slave_id4,1);
  }
  else if (w_r > 0 && w_l < 0)
  {
    rmcs.Enable_Digital_Mode(slave_id1,1);
    rmcs.Enable_Digital_Mode(slave_id2,1);  // Leftward condition
    rmcs.Enable_Digital_Mode(slave_id3,1);
    rmcs.Enable_Digital_Mode(slave_id4,1);
  }

  else if (w_r < 0 && w_l > 0)
  {
    rmcs.Enable_Digital_Mode(slave_id1,0);
    rmcs.Enable_Digital_Mode(slave_id2,0);  // rightward condition
    rmcs.Enable_Digital_Mode(slave_id3,0);
    rmcs.Enable_Digital_Mode(slave_id4,0);
  }

  else
  {
    rmcs.Brake_Motor(slave_id1,0);
    rmcs.Brake_Motor(slave_id2,0);
    rmcs.Brake_Motor(slave_id3,0);
    rmcs.Brake_Motor(slave_id4,0);  // if none of the above break the motors both in clockwise n anti-clockwise direction
    rmcs.Brake_Motor(slave_id1,1);
    rmcs.Brake_Motor(slave_id2,1);
    rmcs.Brake_Motor(slave_id3,1);
    rmcs.Brake_Motor(slave_id4,1);
  }
}
ros::Subscriber<geometry_msgs::Twist> sub("cmd_vel",&messageCb);  // creation of subscriber object sub for recieving the cmd_vel

void setup()
{
  rmcs.Serial_selection(0);  // 0 -> for Harware serial tx1 rx1 of arduino mega
  rmcs.Serial0(9600);
  rmcs.begin(&Serial3, 9600);

  nh.initNode();      // initialzing the node handle object
  nh.subscribe(sub);  // subscribing to cmd vel with sub object

  nh.advertise(left_ticks);   // advertise the left_ticks topic
  nh.advertise(right_ticks);  // advertise the left_ticks topic
}

void loop()
{
  lwheel.data =
      rmcs.Position_Feedback(slave_id4);  // the function reads the encoder value from the motor with slave id 4
  rwheel.data =
      -rmcs.Position_Feedback(slave_id2);  // the function reads the encoder value from the motor with slave id 4

  left_ticks.publish(&lwheel);   // publish left enc values
  right_ticks.publish(&rwheel);  // publish right enc values
  nh.spinOnce();
}

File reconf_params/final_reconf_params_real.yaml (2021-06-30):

!!python/object/new:dynamic_reconfigure.encoding.Config
dictitems:
  acc_lim_theta: 2.5
  acc_lim_trans: 0.1
  acc_lim_x: 0.2
  acc_lim_y: 0.0
  angular_sim_granularity: 0.1
  forward_point_distance: 0.0
  goal_distance_bias: 0.8
  groups: !!python/object/new:dynamic_reconfigure.encoding.Config
    dictitems:
      acc_lim_theta: 2.5
      acc_lim_trans: 0.1
      acc_lim_x: 0.2
      acc_lim_y: 0.0
      angular_sim_granularity: 0.1
      forward_point_distance: 0.0
      goal_distance_bias: 0.8
      groups: !!python/object/new:dynamic_reconfigure.encoding.Config
        state: []
      id: 0
      max_scaling_factor: 0.2
      max_vel_theta: 1.0
      max_vel_trans: 0.2
      max_vel_x: 0.3
      max_vel_y: 0.1
      min_vel_theta: 0.4
      min_vel_trans: 0.07
      min_vel_x: 0.1
      min_vel_y: -0.1
      name: Default
      occdist_scale: 0.01
      oscillation_reset_angle: 0.2
      oscillation_reset_dist: 0.05
      parameters: !!python/object/new:dynamic_reconfigure.encoding.Config
        state: []
      parent: 0
      path_distance_bias: 0.6
      prune_plan: true
      restore_defaults: false
      scaling_speed: 1.0
      sim_granularity: 0.025
      sim_time: 3.0
      state: true
      stop_time_buffer: 0.3
      theta_stopped_vel: 0.1
      trans_stopped_vel: 0.0
      twirling_scale: 0.0
      type: ''
      use_dwa: true
      vth_samples: 25
      vx_samples: 25
      vy_samples: 1
      xy_goal_tolerance: 0.3
      yaw_goal_tolerance: 0.45
    state: []
  max_scaling_factor: 0.2
  max_vel_theta: 1.0
  max_vel_trans: 0.2
  max_vel_x: 0.3
  max_vel_y: 0.1
  min_vel_theta: 0.4
  min_vel_trans: 0.07
  min_vel_x: 0.1
  min_vel_y: -0.1
  occdist_scale: 0.01
  oscillation_reset_angle: 0.2
  oscillation_reset_dist: 0.05
  path_distance_bias: 0.6
  prune_plan: true
  restore_defaults: false
  scaling_speed: 1.0
  sim_granularity: 0.025
  sim_time: 3.0
  stop_time_buffer: 0.3
  theta_stopped_vel: 0.1
  trans_stopped_vel: 0.0
  twirling_scale: 0.0
  use_dwa: true
  vth_samples: 25
  vx_samples: 25
  vy_samples: 1
  xy_goal_tolerance: 0.3
  yaw_goal_tolerance: 0.45
state: []

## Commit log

2021-04-25 rmcs check, publish motor vek after conv.
2021-04-25 before encoder
2021-04-25 with encoder data publish
2021-05-13 urdf
    joint links not working
    [Component3_1.stl, Component3_2.stl, Component3_3.stl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]
2021-06-01 with navigation & map
    [camera_link_v1_1.stl, laser_link_v1_1.stl, navbot.xacro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]
2021-06-02 Final from Jetson
    [Component3_1.stl, Component3_2.stl, Component3_3.stl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]
2021-06-30 test from jetson
2021-06-30 added lidar
    [ydlidar.urdf]
2021-06-30 added ydlidar repo with launch files
    [ydlidar.urdf]
2021-06-30 lidar update
2021-07-01 corrected simulation tf issue
    [navbot_gazebo_plugins.xacro]
2021-07-02 commented and cleaned Arduino code
2022-04-23 Update ARC_2.0.ino
    avoid long button press
    [ARC_2.0.ino]
2023-06-18 hall map
2023-07-18 Update ARC_2.0.ino
    serial port correction as per current hardware wiring
    [ARC_2.0.ino]
